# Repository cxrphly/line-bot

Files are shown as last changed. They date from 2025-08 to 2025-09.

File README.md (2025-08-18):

# Robô Seguidor de Linha Multifuncional com algoritmo PID.

Projeto open-source de um robô seguidor de linha com funções adicionais,como controle via Bluetooth, modos automáticos e manuais, e suporte a sensores extras alem de contar com algoritmo PID para melhor performance no modo seguidor de linha.  
Acompanha **arquivos para impressão 3D**, **corte a laser** e **lista de peças** para montagem.

Repositório: [https://github.com/cxrphly/line-bot](https://github.com/cxrphly/line-bot)

<p align="center">
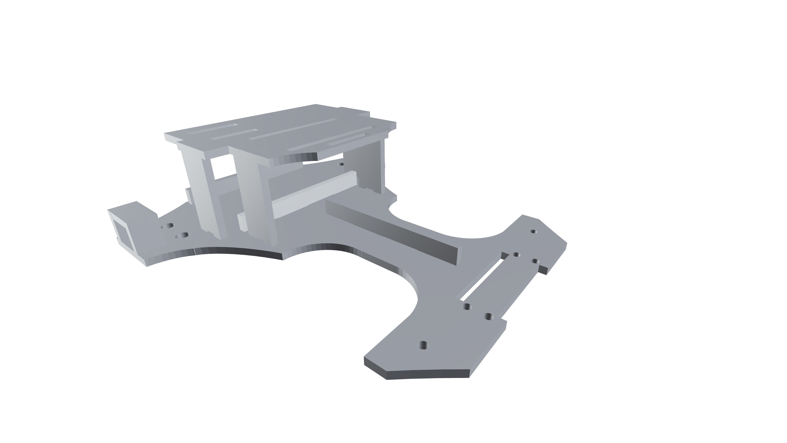
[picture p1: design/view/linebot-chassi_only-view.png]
LineBot Chassi
  
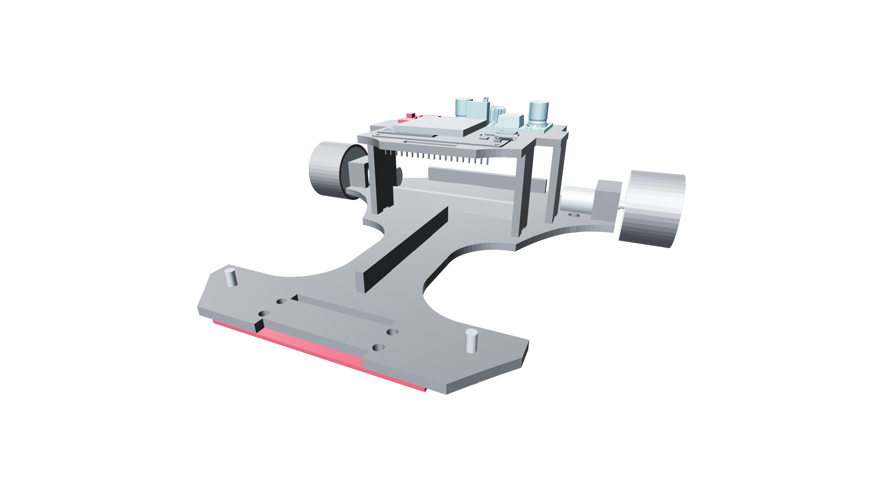
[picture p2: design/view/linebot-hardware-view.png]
LineBot Com Componentes
  
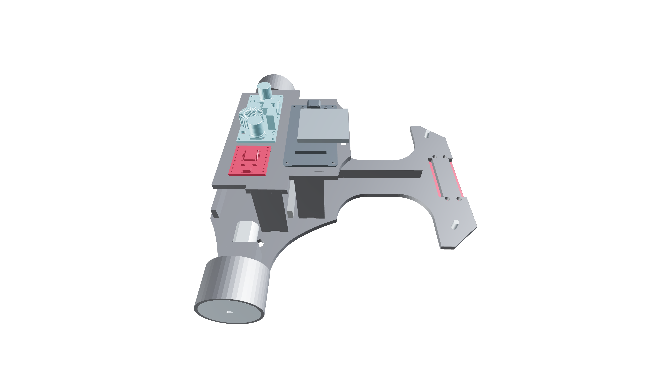
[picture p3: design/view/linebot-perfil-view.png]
LineBot
    
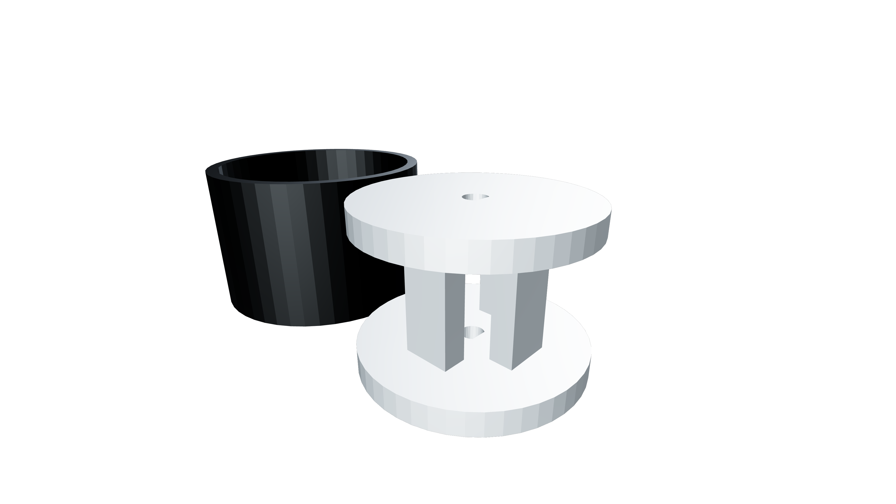
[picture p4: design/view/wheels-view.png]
Rodas LineBot
  
</p>

<p align="center">
  Projeto Montado
</p>

---

## Estrutura do Repositório
- **[main.ino](https://github.com/cxrphly/line-bot/blob/main/main.ino)** → Código-fonte principal para ESP32 (Arduino IDE).  
- **[/design/](https://github.com/cxrphly/line-bot/blob/main/design/)** → Arquivos PDF/SVG para corte a laser e GLB/OBJ para impressão 3D.  

---

## Funcionalidades
- Seguidor de linha com sensor QTR-8A.
- Controle manual via controle Bluetooth (Bluepad32).
- Tela OLED interativa para exibição de informações, alteração de parametros e calibração.  
- Modos de operação (manual e automático).  
- Arquitetura visando expansão dos modulos.

---

## Bibliotecas Utilizadas
- **[Bluepad32]([https://github.com/Bluepad32/Bluepad32](https://github.com/ricardoquesada/bluepad32))** — para suporte a controles Bluetooth no ESP32  
  > Créditos: Ricardo Quesada.
- **[QTRSensor]**
- **[Adafruit SSD1306]**
---

## Lista de Peças Utilizadas
- ESP32 DevKit v1  
- Driver de motor TB6612FNG
- Conversor Buck XL4005E1  
- 2x Motores N20 6V 500RPM
  > Recomendo que use motores de maior RPM para melhor desempenho.
- Sensor QTR-8RC
- Tela OLED I2C 0.96" (128x64)  
- Bateria Li-ion 2S 7.4V 3000mAh 
  >Use um BMS apropriado para evitar descarga extrema
- Breadboard para depuração e pré-montagem  
- Estrutura impressa em 3D ou cortada a laser
  > O projeto, a priori, foi pensado para usar corte a laser, mas com poucas adaptaçôes pode ser impresso em 3d.

---

## Licenças

### Código-fonte
[`LICENSE_CODE`](LICENSE_CODE)

### Arquivos de Design
[`LICENSE_DESIGN`](LICENSE_DESIGN)

---

##
## 1. Certifique-se de que possui instalada em sua máquina a **[Arduino IDE](https://www.arduino.cc/en/software/)** e as bibliotecas necessárias

- i. Adicione **Bluepad32** e **ESP32** ao **[Board Manager](https://bluepad32.readthedocs.io/en/latest/plat_arduino/)**.
- ii. Instale as boards: `ESP32 by Espressif`, `Bluepad32 by Ricardo Quesada`.
- iii. Selecione a placa em **Board -> Other boards** e busque o modelo dentro do escopo da Bluepad32.
   > exemplo: `DOIT ESP32 Dev Kit V1 - esp32_bluepad32`.
- iv. Instale as bibliotecas: `QTRSensors`, `Adafruit SSD1306`, `Adafruit GFX` e `Adafruit BusIO`.

## 2. Clone este repositório:
   ```bash
   git clone https://github.com/cxrphly/line-bot.git
   ```

## 3. Configure os pinos em **[config.h](config.h)**. conforme a sua necessidade, ou matenha padrao.
   ```cpp
   #define AIN1  5
   #define AIN2  18
   #define PWMA  19
   #define BIN1  4
   #define BIN2  2
   #define PWMB  15

   #define CHANNEL_A  0
   #define CHANNEL_B  1
   #define PWM_FREQ     1000
   #define PWM_RES_BITS 8

   #define QTR_D1 14
   #define QTR_D2 27
   #define QTR_D3 26
   #define QTR_D4 25
   #define QTR_D5 33
   #define QTR_D6 32
   #define QTR_D7 35
   #define QTR_D8 34
   #define QTR_IR 13
   ```
## 4. Mapeando o Controle

1. Compile no seu ESP32 o **exemplo Controller** da biblioteca `esp32_bluepad32`.
2. Ligue seu controle Bluetooth em **modo pareamento**; o ESP32 deve se conectar automaticamente ao controle.
3. Abra o **Serial Monitor** e identifique:
   - Os inputs do seu controle (botões, gatilhos, DPAD, etc.)
   - A deadzone dos analógicos
4. Essas informações serão úteis para definir variáveis em **[config.h](config.h)**.

<p align="center">
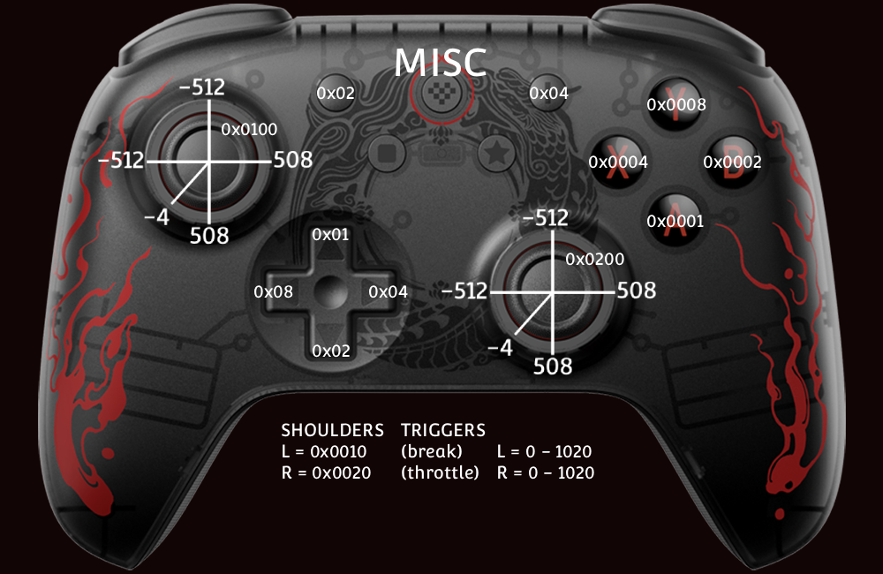
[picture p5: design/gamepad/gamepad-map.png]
8bitdo Ultimate 2C - Já mapeado
  
</p>

## 5. Costomizando o menu(OPCIONAL).
  **Trocando a splash screen**
  **[oled_ui.cpp](oled_ui.cpp)**
   ```cpp
   const unsigned char epd_bitmap_pixil_frame_0_1_ [] PROGMEM = {
        [...]
   };
   const int epd_bitmap_allArray_LEN = 1;
   const unsigned char* epd_bitmap_allArray[1] = {
      epd_bitmap_pixil_frame_0_1_
   };
   ```
  Altere o conteudo por qualquer bitmap(dë preferencia à 128x48) usando **[img2cpp](https://javl.github.io/image2cpp/)** ou outra ferramenta.

## 6. Sobre a Bluepad32  
  A documentacao no site oficial é limitada, recomendo ver os codigo-exemplo em File > Exemples > Bluepad32_ESP32.  
  Caminho no windows para algumas keywords:  
   ```
   C:\Users\user\AppData\Local\Arduino15\packages\esp32-bluepad32\hardware\esp32\4.1.0\libraries\Bluepad32_ESP32
   ```
- keywords.txt
```bash
#######################################
# Syntax Coloring Map For WiFiNINA
#######################################

#######################################
# Library (KEYWORD1)
#######################################

Controller KEYWORD1
Gamepad KEYWORD1
Bluepad32 KEYWORD1
BP32 KEYWORD1

#######################################
# Methods and Functions (KEYWORD2)
#######################################

# Bluepad32
firmwareVersion KEYWORD2
setDebug KEYWORD2
pinMode KEYWORD2
digitalRead KEYWORD2
digitalWrite KEYWORD2

# Gamepad
update KEYWORD2
forgetBluetoothKeys KEYWORD2
setup KEYWORD2
a KEYWORD2
b KEYWORD2
x KEYWORD2
y KEYWORD2
l1 KEYWORD2
l2 KEYWORD2
r1 KEYWORD2
r2 KEYWORD2
thumbL KEYWORD2
thumbR KEYWORD2
buttons KEYWORD2
miscButtons KEYWORD2
axisX KEYWORD2
axisY KEYWORD2
axisRX KEYWORD2
axisRY KEYWORD2
brake KEYWORD2
throttle KEYWORD2
miscSystem KEYWORD2
miscBack KEYWORD2
miscHome KEYWORD2
isConnected KEYWORD2
getModel KEYWORD2
setPlayerLEDs KEYWORD2
setColorLED KEYWORD2
setRumble KEYWORD2

#######################################
# Constants (LITERAL1)
#######################################

# Controllers
CONTROLLER_TYPE_UnknownSteamController LITERAL1
CONTROLLER_TYPE_SteamController LITERAL1
CONTROLLER_TYPE_SteamControllerV2 LITERAL1
CONTROLLER_TYPE_UnknownNonSteamController LITERAL1
CONTROLLER_TYPE_XBox360Controller LITERAL1
CONTROLLER_TYPE_XBoxOneController LITERAL1
CONTROLLER_TYPE_PS3Controller LITERAL1
CONTROLLER_TYPE_PS4Controller LITERAL1
CONTROLLER_TYPE_WiiController LITERAL1
CONTROLLER_TYPE_AppleController LITERAL1
CONTROLLER_TYPE_AndroidController LITERAL1
CONTROLLER_TYPE_SwitchProController LITERAL1
CONTROLLER_TYPE_SwitchJoyConLeft LITERAL1
CONTROLLER_TYPE_SwitchJoyConRight LITERAL1
CONTROLLER_TYPE_SwitchJoyConPair LITERAL1
CONTROLLER_TYPE_SwitchInputOnlyController LITERAL1
CONTROLLER_TYPE_MobileTouch LITERAL1
CONTROLLER_TYPE_XInputSwitchController LITERAL1
CONTROLLER_TYPE_PS5Controller LITERAL1
CONTROLLER_TYPE_iCadeController LITERAL1
CONTROLLER_TYPE_SmartTVRemoteController LITERAL1
CONTROLLER_TYPE_EightBitdoController LITERAL1
CONTROLLER_TYPE_GenericController LITERAL1
CONTROLLER_TYPE_NimbusController LITERAL1
CONTROLLER_TYPE_OUYAController LITERAL1

# DPAD
DPAD_UP LITERAL1
DPAD_DOWN LITERAL1
DPAD_RIGHT LITERAL1
DPAD_LEFT LITERAL1

# Buttons
BUTTON_A LITERAL1
BUTTON_B LITERAL1
BUTTON_X LITERAL1
BUTTON_Y LITERAL1
BUTTON_SHOULDER_L LITERAL1
BUTTON_SHOULDER_R LITERAL1
BUTTON_TRIGGER_L LITERAL1
BUTTON_TRIGGER_R LITERAL1
BUTTON_THUMB_L LITERAL1
BUTTON_THUMB_R LITERAL1

# Misc buttons
MISC_BUTTON_SYSTEM LITERAL1
MISC_BUTTON_BACK LITERAL1
MISC_BUTTON_HOME LITERAL1
 ```

---

## Agradeço a comunidade open-source por tornar esse projeto possivel.

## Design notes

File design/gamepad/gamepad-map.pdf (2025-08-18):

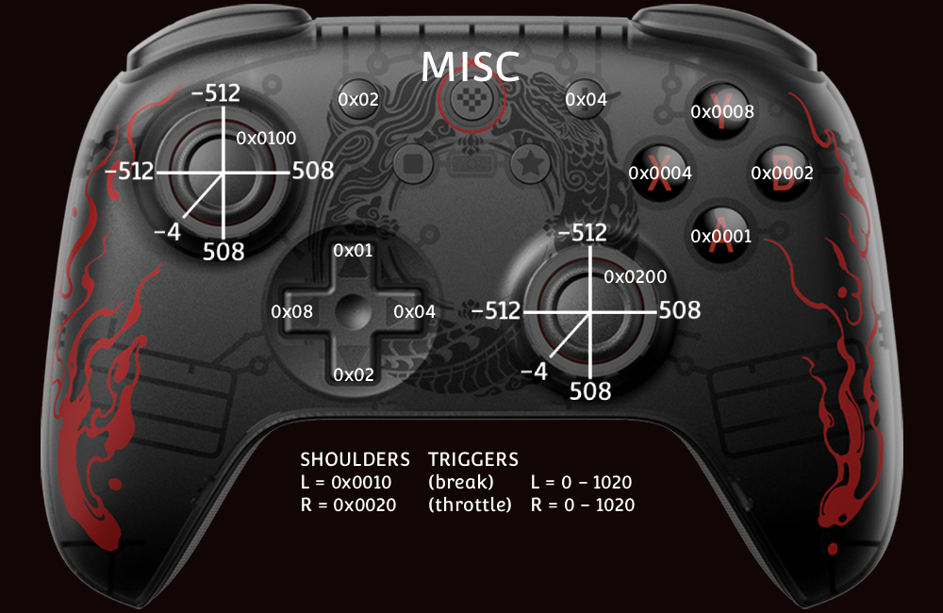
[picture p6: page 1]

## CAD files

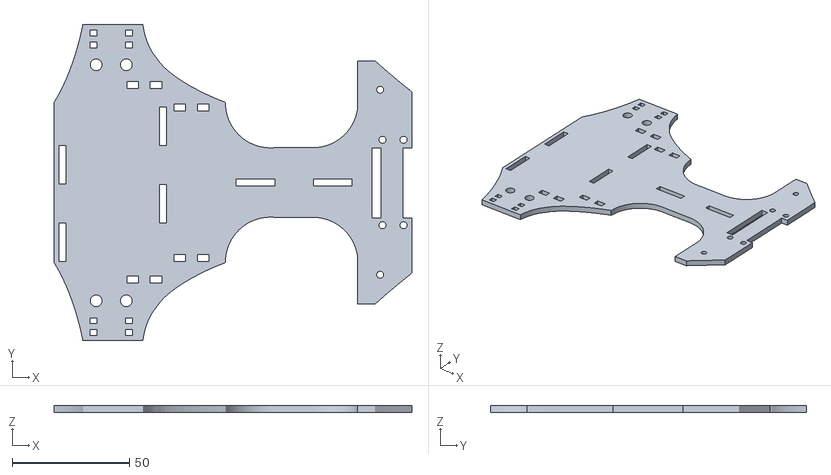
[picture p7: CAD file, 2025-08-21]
design/3d/parts/1x_main_base.stl
152.9 x 135.1 x 3.00

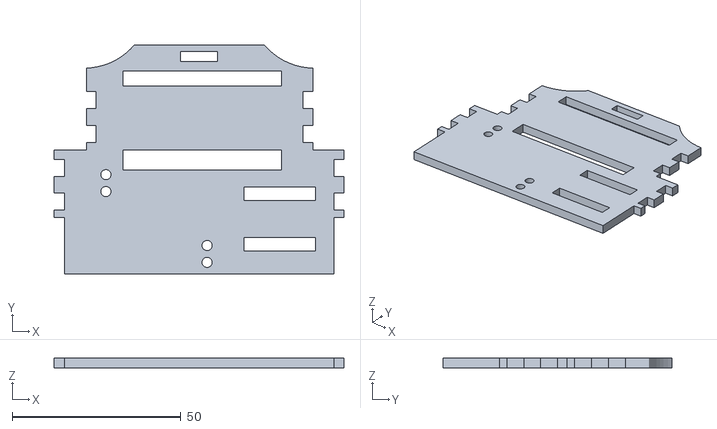
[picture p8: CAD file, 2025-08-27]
design/3d/parts/1x_sup_base.stl
86.0 x 68.0 x 3.00

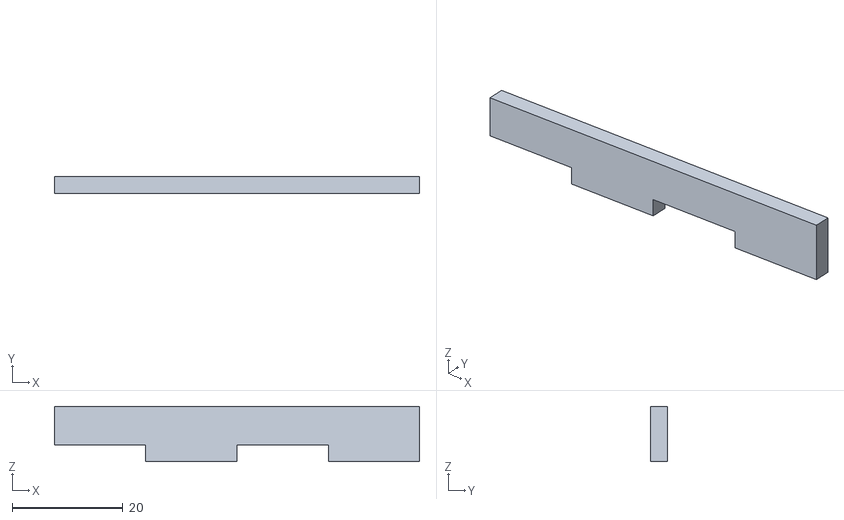
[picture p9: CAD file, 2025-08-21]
design/3d/parts/3x_reinforce.stl
66.0 x 3.00 x 10.0

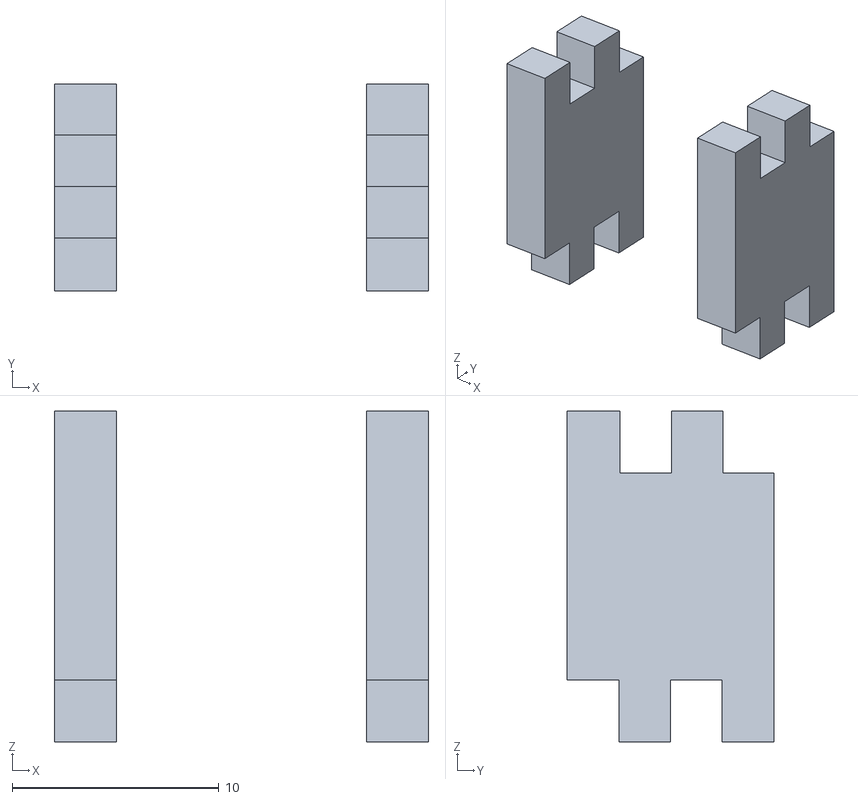
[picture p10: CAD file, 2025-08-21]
design/3d/parts/2x_motor-lateral.stl
18.1 x 10.00 x 16.0

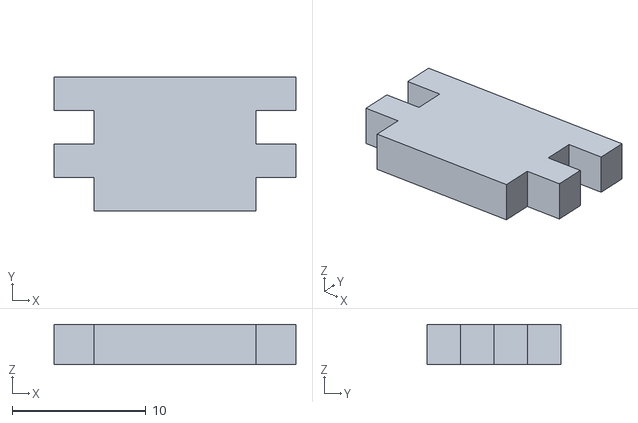
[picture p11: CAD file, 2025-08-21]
design/3d/parts/2x_motor-superior.stl
18.1 x 10.0 x 3.00

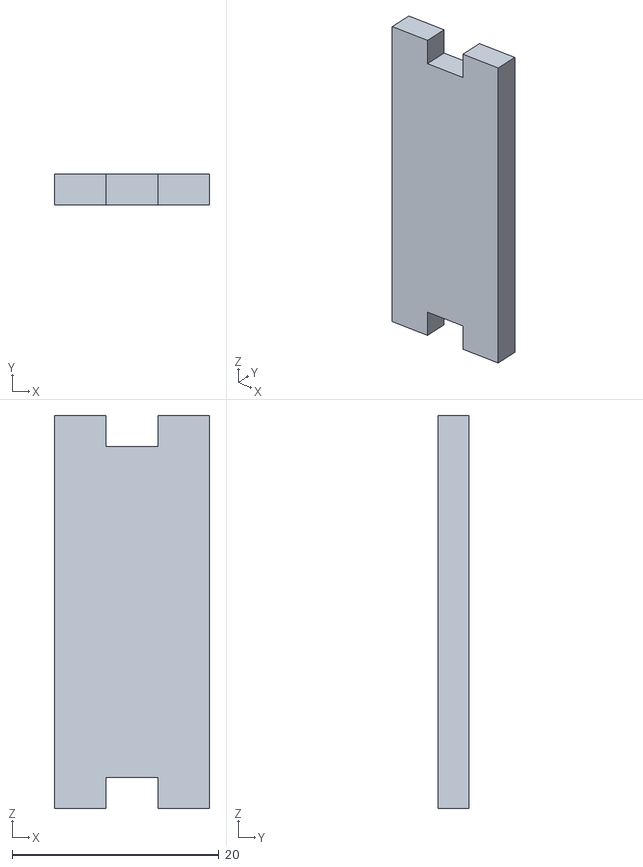
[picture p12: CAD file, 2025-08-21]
design/3d/parts/4x_collunm.stl
15.0 x 3.00 x 38.0

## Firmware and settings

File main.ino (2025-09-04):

#include "Config.h"
#include "OLED_UI.h"
#include "Motors.h"
#include "LineFollower.h"
#include "Gamepad.h"

Adafruit_SSD1306 display(SCREEN_WIDTH, SCREEN_HEIGHT, &Wire, OLED_RESET);

ControllerPtr myControllers[BP32_MAX_GAMEPADS] = {nullptr};

int maxSpeed = 200;
float Kp = 0.05f;
float Kd = 0.25f;
float Ki = 0.05f;
float lastError = 0;
int threshold = 900;
float filteredError = 0;

AppState appState = STATE_SPLASH;

int menuIndex = 0;
bool lineFollowerActive = false;
bool controllerModeActive = false;

const int menuItemCount = 5;
const char* menuItems[] = {
  "@Line Follower",
  "$Manual",
  "@Ver Eixos",
  "@Ver Botoes",
  "Configurar"
  };

int lfMenuIndex = 0;
const int lfMenuItemCount = 3;
const char* lfMenuItems[] = {
  "$Ativar",
  "#Calibrar",
    "Configurar"
  };

int cfgMenuIndex = 0;
const int cfgMenuItemCount = 5;
const char* cfgMenuItems[] = {
    "Kp",
    "Ki",
    "Kd",
    "Treshold",
    "MaxSpeed"
};
unsigned long lastDebug = 0;
const unsigned long debugInterval = 100;
unsigned long lastInputTime = 0;
const unsigned long inputDelay = 200;

void setup() {
  Serial.begin(115200);
  setupQTR();
  loadConfig();
  pinMode(AIN1, OUTPUT);
  pinMode(AIN2, OUTPUT);
  pinMode(BIN1, OUTPUT);
  pinMode(BIN2, OUTPUT);

  ledcSetup(CHANNEL_A, PWM_FREQ, PWM_RES_BITS);
  ledcAttachPin(PWMA, CHANNEL_A);
  ledcSetup(CHANNEL_B, PWM_FREQ, PWM_RES_BITS);
  ledcAttachPin(PWMB, CHANNEL_B);

  if(!display.begin(SSD1306_SWITCHCAPVCC, SCREEN_ADDRESS)) while(true);
  display.clearDisplay();
  display.display();


  BP32.setup(&onConnectedController, &onDisconnectedController);
}

void loop() {
    BP32.update();
    processCalibration();

    bool controleConectado = false;
    for (int i = 0; i < BP32_MAX_GAMEPADS; i++) {
        if (myControllers[i] && myControllers[i]->isConnected()) {
            processGamepad(myControllers[i]);
            controleConectado = true;
            break;
        }
    }

    if (!controleConectado) {
        showSplashScreen();
    }

    if (lineFollowerActive) {
        lineFollowerControl();
    } 
    else if (controllerModeActive) {
        for (int i = 0; i < BP32_MAX_GAMEPADS; i++) {
            if (myControllers[i] && myControllers[i]->isConnected()) {
                controlMotors(myControllers[i]); 
                break;
            }
        }
    } 
    else {
        setMotor(0, 0);
    }
}

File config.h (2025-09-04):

#pragma once
#include <Arduino.h>
#include <Bluepad32.h>

#define SCREEN_WIDTH 128
#define SCREEN_HEIGHT 64
#define OLED_RESET -1
#define SCREEN_ADDRESS 0x3C

#define MISC_BUTTON_HOME 0x01
#define MISC_BUTTON_START 0x04
#define MISC_BUTTON_SELECT 0x02

#define AIN1  5
#define AIN2  18
#define PWMA  19
#define BIN1  4
#define BIN2  2
#define PWMB  15

#define CHANNEL_A  0
#define CHANNEL_B  1
#define PWM_FREQ     1000
#define PWM_RES_BITS 8

#define QTR_D1 14
#define QTR_D2 27
#define QTR_D3 26
#define QTR_D4 25
#define QTR_D5 33
#define QTR_D6 32
#define QTR_D7 35
#define QTR_D8 34
#define QTR_IR 13
constexpr uint8_t SensorCount = 8;

extern int maxSpeed;
extern float Kp;
extern float Kd;
extern float Ki;
extern float lastError;
extern int threshold;
extern float filteredError;

enum AppState {
  STATE_SPLASH,
  STATE_MENU,
  STATE_EIXOS,
  STATE_BOTOES,
  STATE_LINEFOLLOWER_MENU,
  STATE_CONFIG_MENU
};
extern AppState appState;

extern int menuIndex;
extern bool lineFollowerActive;
extern bool controllerModeActive;

extern const int menuItemCount;
extern const char* menuItems[];

extern int lfMenuIndex;
extern const int lfMenuItemCount;
extern const char* lfMenuItems[];

extern int cfgMenuIndex;
extern const int cfgMenuItemCount;
extern const char* cfgMenuItems[];

extern unsigned long lastDebug;
extern const unsigned long debugInterval;

extern unsigned long lastInputTime;
extern const unsigned long inputDelay;

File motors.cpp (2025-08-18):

#include "motors.h"
#include "Config.h"
#include <Arduino.h>

void controlMotors(ControllerPtr ctl) {
  int ly = -ctl->axisY();
  int lx =  ctl->axisX();

  int speed = map(ly, -512, 512, -255, 255);
  int turn  = map(lx, -512, 512, -255, 255);

  int right = constrain(speed + turn, -255, 255);
  int left  = constrain(speed - turn, -255, 255);

  setMotor(left, right);
}

void setMotorRawA(int pwm, bool forward) {
    digitalWrite(AIN1, forward ? HIGH : LOW);
    digitalWrite(AIN2, forward ? LOW : HIGH);
    ledcWrite(CHANNEL_A, pwm);
}

void setMotorRawB(int pwm, bool forward) {
    digitalWrite(BIN1, forward ? HIGH : LOW);
    digitalWrite(BIN2, forward ? LOW : HIGH);
    ledcWrite(CHANNEL_B, pwm);
}

void setMotor(int leftSpeed, int rightSpeed) {
    leftSpeed  = constrain(leftSpeed,  -255, 255);
    rightSpeed = constrain(rightSpeed, -255, 255);

    setMotorRawB(abs(leftSpeed), leftSpeed >= 0);
    setMotorRawA(abs(rightSpeed), rightSpeed >= 0);
}

void setupMotors() {
    pinMode(AIN1, OUTPUT);
    pinMode(AIN2, OUTPUT);
    pinMode(BIN1, OUTPUT);
    pinMode(BIN2, OUTPUT);

    ledcSetup(CHANNEL_A, PWM_FREQ, PWM_RES_BITS);
    ledcAttachPin(PWMA, CHANNEL_A);
    ledcSetup(CHANNEL_B, PWM_FREQ, PWM_RES_BITS);
    ledcAttachPin(PWMB, CHANNEL_B);
}

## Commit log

2025-08-21 design fix
    [1x_main_base.stl, 1x_sup_base.stl, 2x_motor-lateral.stl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]
2025-08-27 design, config and readme updated
    [1x_sup_base.stl]
